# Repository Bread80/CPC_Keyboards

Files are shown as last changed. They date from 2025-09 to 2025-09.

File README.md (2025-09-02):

# Keyboards for Amstrad CPC Computers

This folder contains several designs for Amstrad computers, CPC464, CPC664 and CPC6128. Some can be fitted into the case of an existing machine, all can be used without a case as a replacement for, eg, a bare motherboard including recreations of original motherboards of replacement machines which use the same keyboard layout.

All of the above machines, CPC464, CPC664 and CPC6128, used an identical keyboard matrix although they had slight variations in connectors and pinouts. All of the boards here are suitable for using with any original motherboard. Most of the designs include jumpers or links which can be used to configure them to various mnotherboards. See the individual boards for more detail.

## Available Boards

### [Tactile Switch Keyboard](Tactile/README.md)

This was intended as a cheaper alternative to a full mechanical board. In practice the switches and keycaps used don't offer a huge saving in cost. However, the PCB is significantly smaller (and therefore cheaper), the design doesn't use diodes, and the keycaps can be home-printed and, therefore, modified to your preference.

This design is not (currently) fully documented.

[View...](Tactile/README.md)

### [CPC464 Mechanical with SMT Diodes](Keyswitch_CPC464_SMT/README.md)

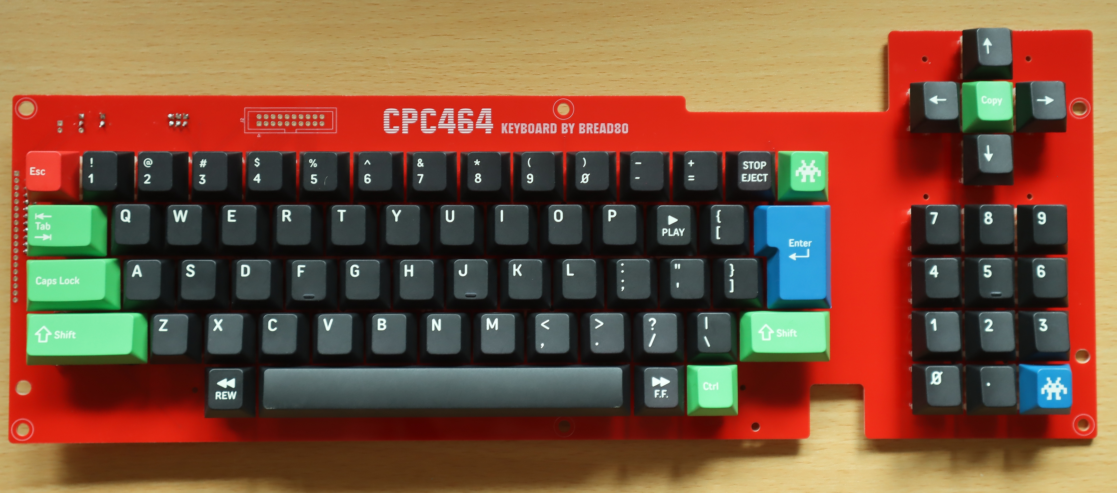
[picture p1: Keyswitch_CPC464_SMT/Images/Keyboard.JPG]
Assembled keyboard


As the heading suggests, this is a board using mechanical keyswitches, and which fits into an original CPC464 case (all variants, as far as we are aware). It includes connector pinouts for both styles of motherboard connector. Solder links allow for use with a CPC6128. See the schematics for how to wire to a CPC664.

The design uses SMT diodes which may present a soldering challenge to some, but the diodes and footprints have been chosen to make soldering as easy as possible.

[View...](Keyswitch_CPC464_SMT/README.md)

### [CPC6128 Mechanical with SMT Diodes](Keyswitch_CPC6128_SMT/README.md)

This board is still at the design stage and NOT suitable for production.

[View...](Keyswitch_CPC6128_SMT/README.md)

## Licence

All designs are licenced under CERN-OHL-P.

You are welcome you sell items for cost plus reasonable postage fees. This allows you to pass on any overages from your PCB fab's minumum order levels. If you want to sell items for profit please talk to us first.

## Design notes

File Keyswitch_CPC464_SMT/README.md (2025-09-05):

# CPC464 Mechanical Keyboard (with SMT Diodes)

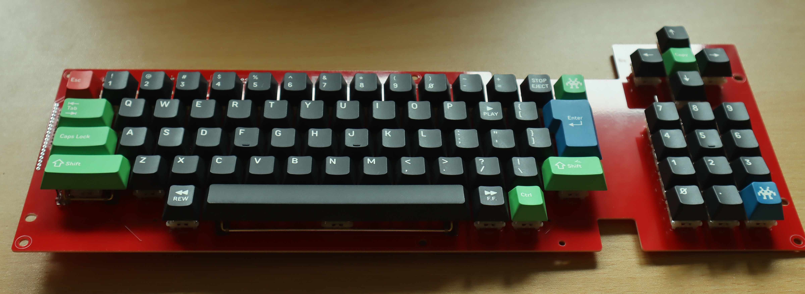
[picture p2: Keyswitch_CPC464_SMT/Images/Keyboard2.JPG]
Assembled keyboard
Assembled keyboard

This project is for an replacement keyboard for an Amstrad CPC464 using Cherry MX compatible keyswitches.

The board is suitable for mounting within an existing CPC464 case and includes connections suitable for both the single row 19/20-pin inline PCB type keyboard and the dual 10-pin connectors used by later membrane keyboards. It can also be used free standing, either with a CPC464 or CPC6128 - jumpers footprints are included to allow remapping of the dual 10-pin connectors. (The keyboard could also be used with a CPC664 but the lines will need remapping between the keyboard and motherboard. The schematic includes details). A third connector footprint is provided at the rear of the board with identical pinout to the 2x10-pin connector (and remapped via the same jumpers). This connector is intended to make the PCB easier to use as a free-standing board when, for example, using with a bare motherboard outside of a case.

Footprints allow either direct soldering of the keyswitches to the board, or the use of MX hotswap sockets. Hotswap sockets allow keyswitches to be more easily swapped for different types or between boards. The board accepts either 3-pin or 5-pin keyswitches but NOTE: There is currently no mounting plate available. We therefore recommend only using 5-pin keyswitches, and NOT 3-pin ones (5-pin switches have two extra mounting lugs on the rear).

The space bar has been reduced in width from the original 9u to a modern standard 7u. The space freed by this has allowed the addition of two 'bonus' keys. These can be mapped, via jumpers, to the main connectors for reading by the host computer, or can be connected to external hardware via the same jumpers.

When fitted into an Amstrad CPC464 case there is a slight gap (0.5u wide, where 1u is one standard key width) to the right of the Enter key. This is, sadly, unavoidable due to available keycap sizes.

## Purchase PCBs

You can download the gerbers from within the repository or purchase PCBs via PCBWay Shared Projects at https://www.pcbway.com/project/shareproject/Mechanical_Keyboard_for_Amstrad_CPC464_e66db4b2.html Disclaimer: we get a small commission if you purchase from PCBWay Shared Projects. This commission helps to fund our other open source projects.

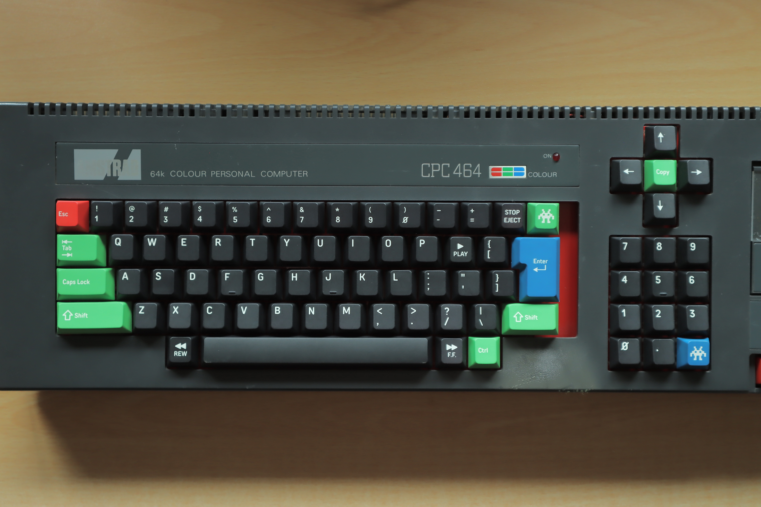
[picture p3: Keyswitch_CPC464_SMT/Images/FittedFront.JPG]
Keyboard fitted into a CPC464 (top view)
Keyboard fitted into a CPC464 (rear view)

## Bill or Materials (BoM)

(This list does not include connectors. See the section below for some connection options).

|Reference|Value|Package|Qty|Notes|
|---|-----|---|---|-----|
|D0-D71,D79,D901,D902|1N4148W|SOD-123|75|If buying from a specialist mechanical keyboard retailer these will be the only surface mount diodes available. We recommend buying a few spares as these are very small and easy to lose.|
|SW0-SW71,SW79,SW901,SW902|MX Hotswap Sockets||75|Optional. Make sure you get the MX type.|
|SW0-SW71,SW79,SW901,SW902|MX Compatible keyswitches||75|Lots of options available. As noted above these should be 5-pin switches.|
|SW0-SW71,SW79,SW901,SW902|MX Compatible keycaps||75|Again of options available. See below for some advice.|
|ST1,ST2|Stabiliser 2u|PCB Mount|2|Use 'PCB Mount'/'screw in' type (NOT plate mount)	Stabilisers are usually supplied in sets which include all necessary parts including mounting screws. Each set will contain more than you need to this project, but make sure you get a set which includes a 7u wire for the space bar.|
|ST3|Stabiliser 7u|PCB Mount|1|(See notes for 2u stabilisers above).|

### Feet

If the board is used free-standing you will probably want to add some feet. The board includes 6(No) M3 mounting holes suitable for this. We would suggest rubber feet at the front and stand-offs at the rear (possibly with rubber feet on the end) to provide some 'raking' to the board.

## Assembly

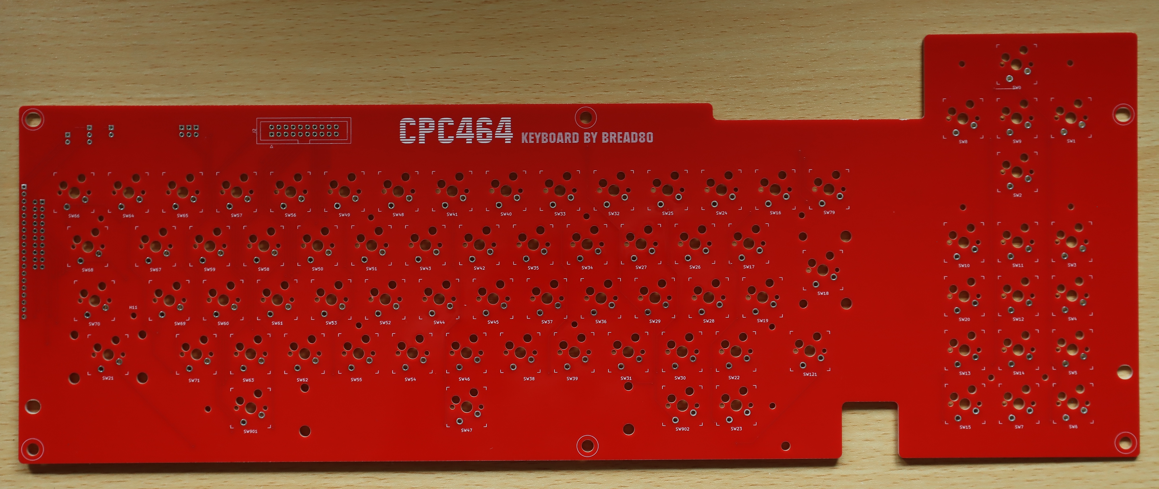
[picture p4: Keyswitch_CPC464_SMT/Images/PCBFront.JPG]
PCB front
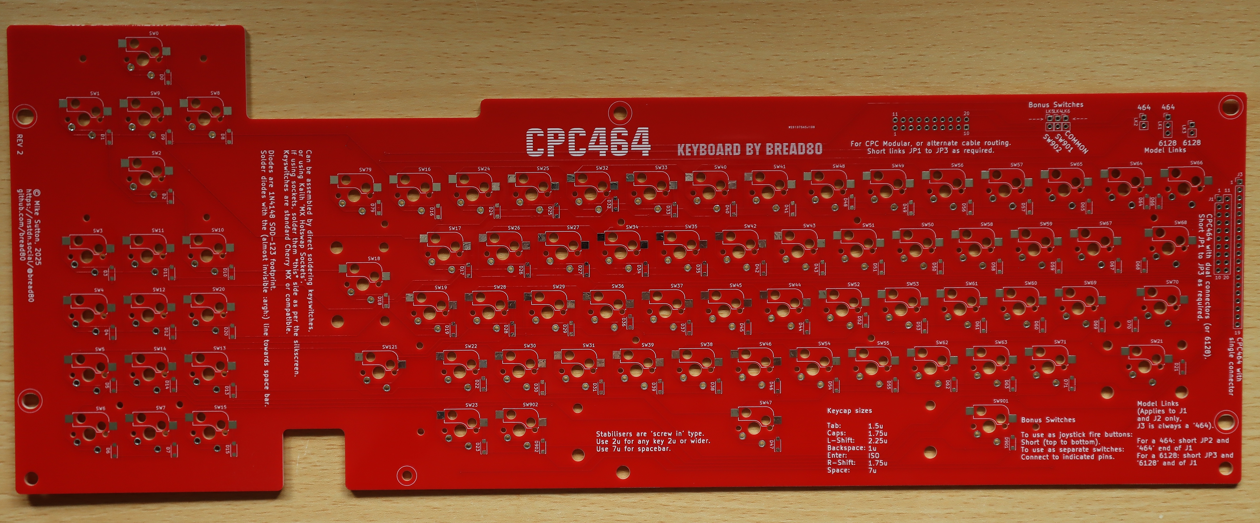
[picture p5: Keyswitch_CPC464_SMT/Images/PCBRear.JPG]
PCB rear

Rear detail

Begin by orienting yourself to the board and, in particular, which side is the top and which the bottom. The top of the board boards the square outlines of the keyswitches, the bottom has the footprints for the hotswap sockets and diodes. Diodes, hotswap sockets (if used) and keyswitches (if not using sockets) are all soldered to the bottom of the board.

We suggest the following assembly sequence.

1. Diodes

Diodes must be installed in the correct orientation. If examined closely you will notice a white line across one end of the diode. On the PCB this end all the diodes must point towards the front (space bar end) of the board. It might be wise to test a few with a multimeter to verify you are have this correct.

2. Hotswap sockets (if using them)

Orient each socket to match the silkscreen and so that the two lugs occupy the holes, then solder each pin.

It's worthwhile checking each socket is fully seated into the board by reheating each pin which pushing the socket with a finger - but take care not to burn your finger! We like to solder all the sockets, then go over one end of every socket. Then, once they have cooled, do the same for the other end of every socket.

3. Connectors and Jumpers (depending on your chosen options - see below)

For jumpers use some wire offcuts - perhaps resistor leads from a previous project?

4. Stabilisers

Check the manufacturers instructions. Pre-assembled ones are fairly straightforward, others are an IQ test which we often fail at on the first go. If the key doesn't press down properly you failed too.

5. Keyswitches (if not using sockets)

These are pretty straightforward. Insert each so that the pins are located in the plated (metalised) holes and fully pushed 'home'. Solder both pins. Double check they are fully seated and, if necessary, reheat while pushing down on the switch.

6. Keyswitches (if using sockets)

This one is easy! Insert the keyswitches, but make sure the pins are mounted into the sockets (this may sound dumb, but they are easily bent).

## Jumper Settings

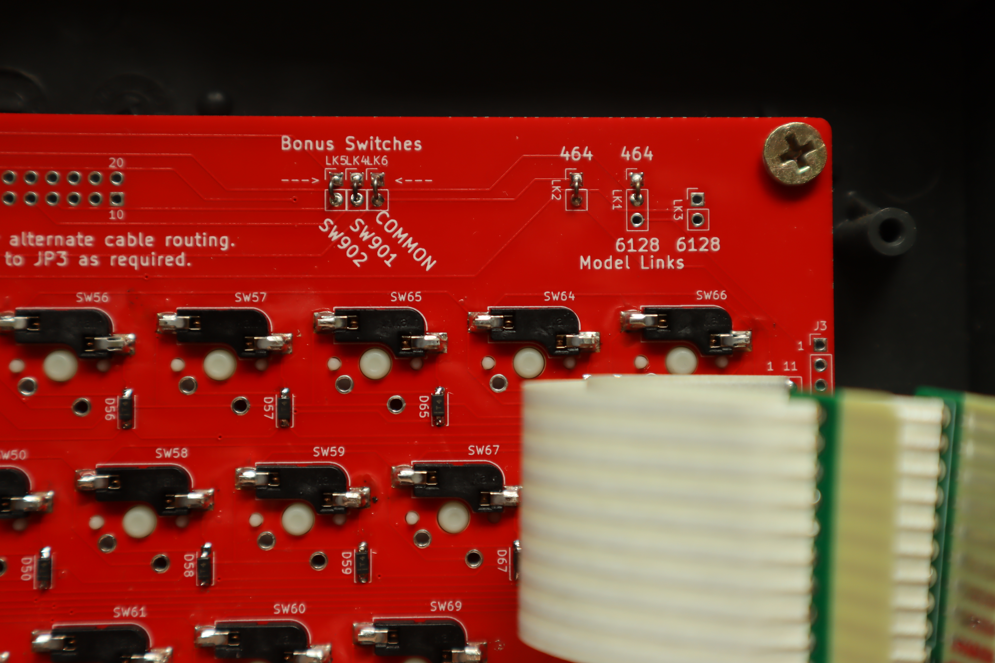
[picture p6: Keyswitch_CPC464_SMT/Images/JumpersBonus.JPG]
Bonus switches and jumpers detail


'Bridging' a solder link entails soldering some bare wire between two pins on the link.

If connecting to a '464 bridge LK2 and the two pins at the '464' end of LK1 (as shown in the photo).

If connecting to a '6128 bridge LK3 and the two pins at the '6128' end of LK3.

(If using the board freestanding and want the flexibility to move it between computers you could also use pin-header with 'shunts' to bridge them. If so you may want to locate them on the top-side of the board).

## Bonus Switches

To map the bonus switches to joystick 1 fire buttons, short the connectors as shown in the photo.

To use as separate switches make connections to three holes indicated by the arrows.

## Installation

The keyboard is attached to the case with five or six screws (depending on the case revision) and replacement is straightforward. Take care not to overtighten the screws as the threads in the plastic case are easy to strip.

The spade terminal ground connection cannot be connected to the new PCB and will need to be covered with electrical insulation tape or similar to prevent it shorting anything.

## Connecting to the motherboard

Connection options depend on your motherboard revision. We are open to feedback and suggestions for better options.

### Single Row Motherboards (PCB style keyboards)

Amstrad appear to have used two different connector styles over the life of the machine. Sadly neither of these seem to be still available. The best option is probably replacing the motherboard header with something which is available, and directly soldering wires to the keyboard PCB (as per original Amstrad keyboards).

### Double Row Motherboards (membrane style keyboards)

PCBs are available which can slot into the motherboard connectors. We have our own available at https://github.com/Bread80/Keyboard-FPC10  The motherboard connectors are single sided and the PCBs will need to be assembled to match. Note that these PCBs must be manufactured to a suitable thickness for inserting into the sockets.

Our preference is to use FFC/FPC cables (with 2.54mm pin pitch) to connect these to the keyboard, the other end being direct soldered to the board.

## Keycaps

There is, obviously, a wide selection of keycaps available. In the board shown in the photos we've used the lovely Amstrad inspired set available at https://finalkeystudio.com/products/amstrad-cpc-464-keycaps-set which has both '464 and '6128 inspired options. Sadly the set  doesn't cover ever key you'll need (note the CLR and DEL keys in the photos) but there are plenty of other keys which can be used to substitute. The set also uses 'standard' layout for (eg) symbols rather than (any of) the Amstrad layout(s). (We have no connection to the designer or seller, and can't offer buying advice, but we do love the keycaps).

When selecting a set you'll need one which includes the following key widths:
|Key|Width|
|---|-----|
|Tab|1.5u|
|Caps|1.75u|
|Left Shift|2.25u|
|Backspace|1u|
|Enter|ISO standard|
|Right Shift|1.75u|
|Space bar|7u|

It's also worth noting that you're unlikely to find a set which matches the Amstrad symbol layout. If rearranging keys note that keycap profiles are different for every row and swapping keys between rows may not be ideal.

Rather than re-arranging the keys the Amstrad firmware has support for remapping the layout in software. This is (currently) left as an exercise for the reader.

## Schematic

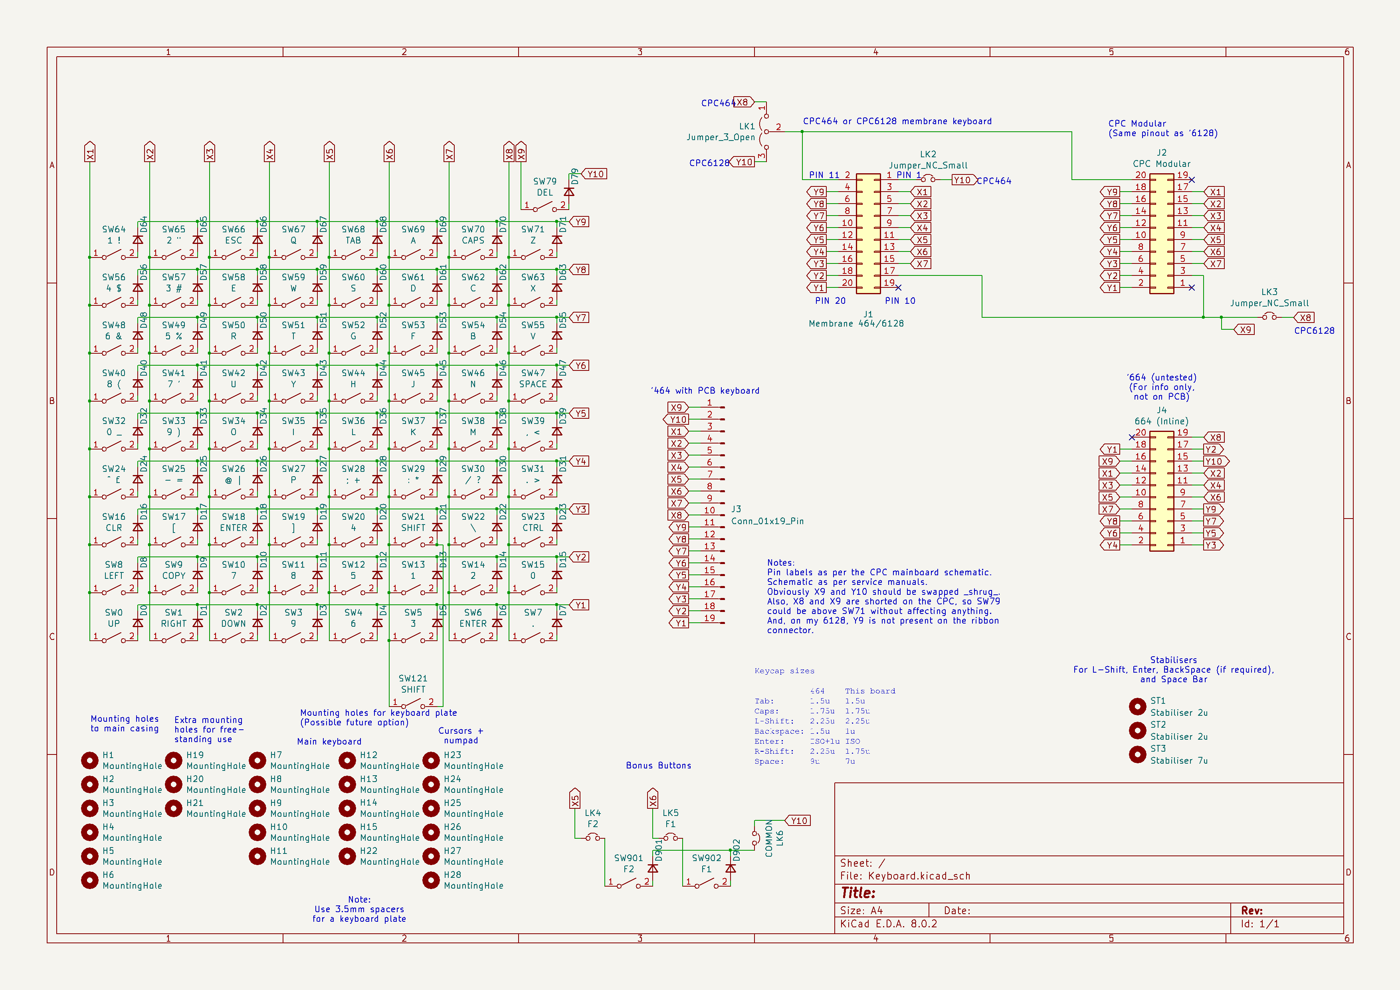
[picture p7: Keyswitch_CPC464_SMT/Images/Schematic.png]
Schematic


## Licence

CERN-OHL-P

You are welcome you sell items for cost plus reasonable postage fees. This allows you to pass on any overages from your PCB fab's minimum order levels. If you want to sell items for profit please talk to us first.

## More Images

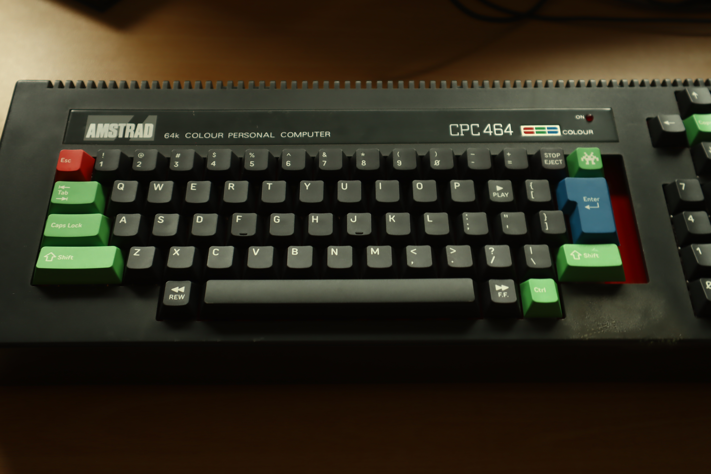
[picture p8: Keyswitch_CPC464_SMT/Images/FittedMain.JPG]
Fitted main section

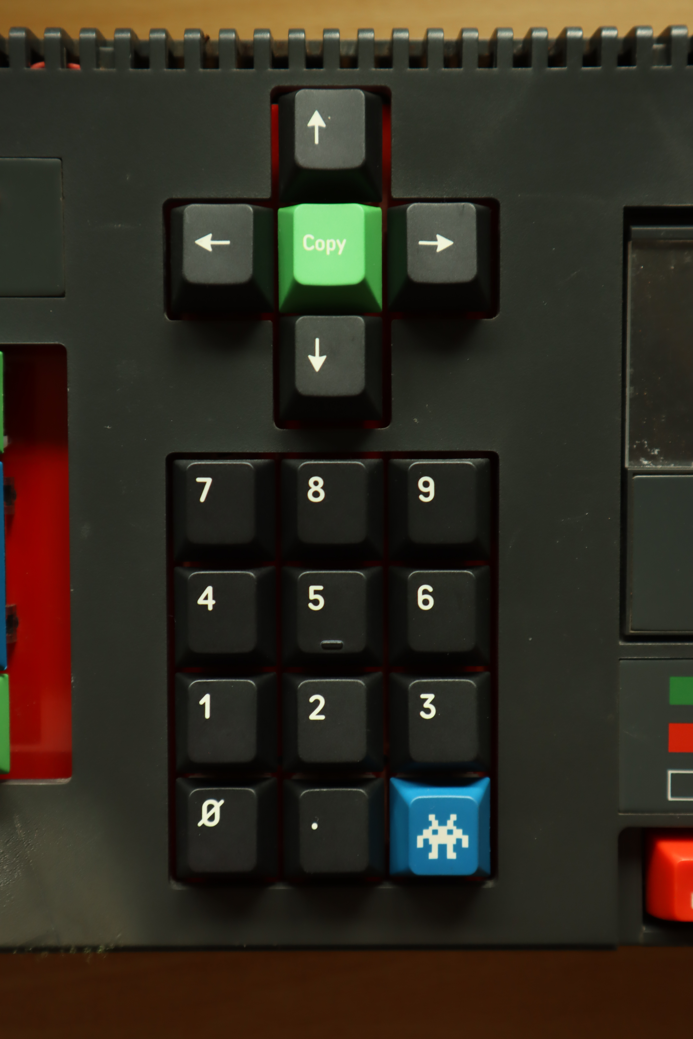
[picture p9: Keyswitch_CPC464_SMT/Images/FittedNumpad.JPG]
Fitted number pad

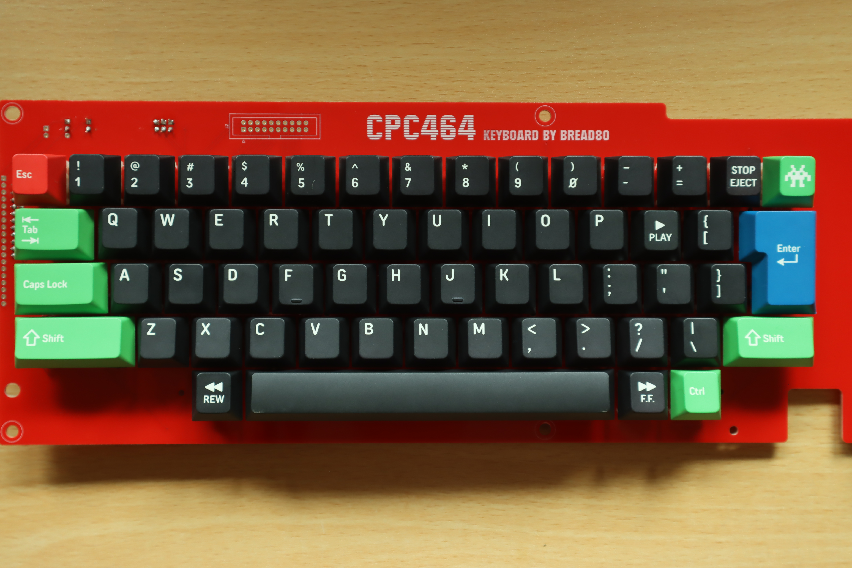
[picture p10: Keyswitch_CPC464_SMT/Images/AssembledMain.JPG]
Assembled main section

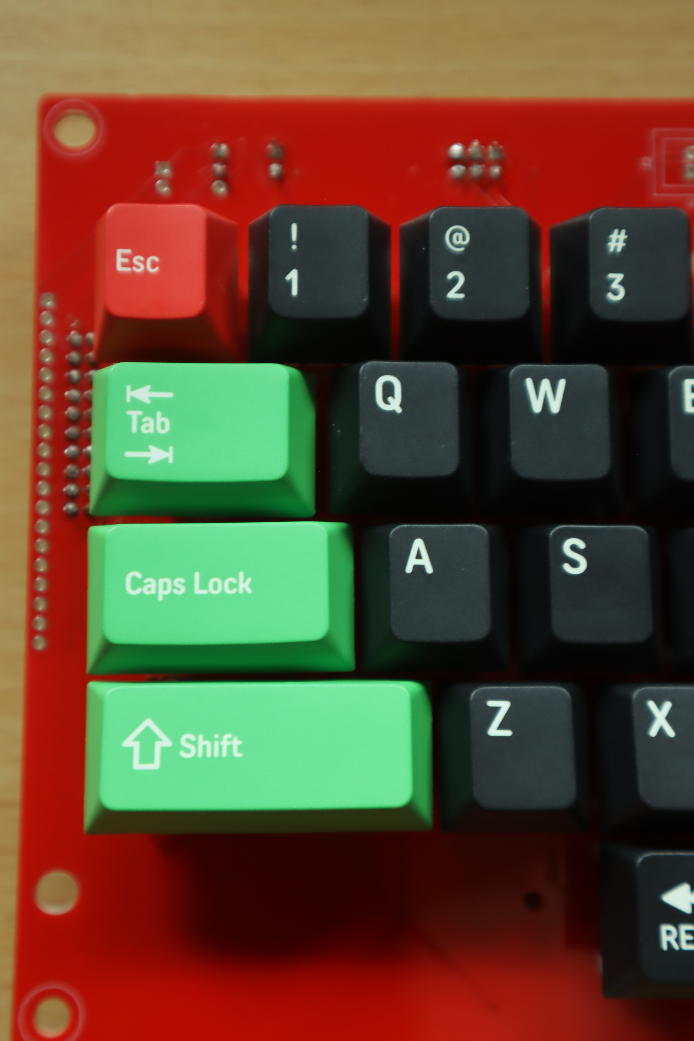
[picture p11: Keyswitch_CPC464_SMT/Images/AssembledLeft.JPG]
Left end of assembled board

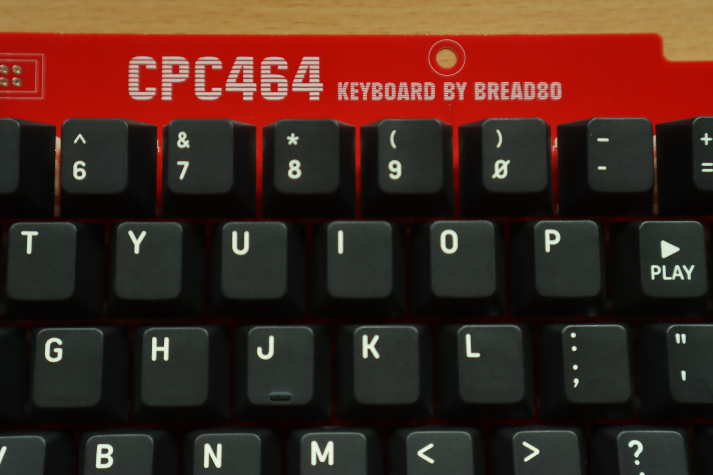
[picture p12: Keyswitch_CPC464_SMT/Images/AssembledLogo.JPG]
Detail of logo on assembled board

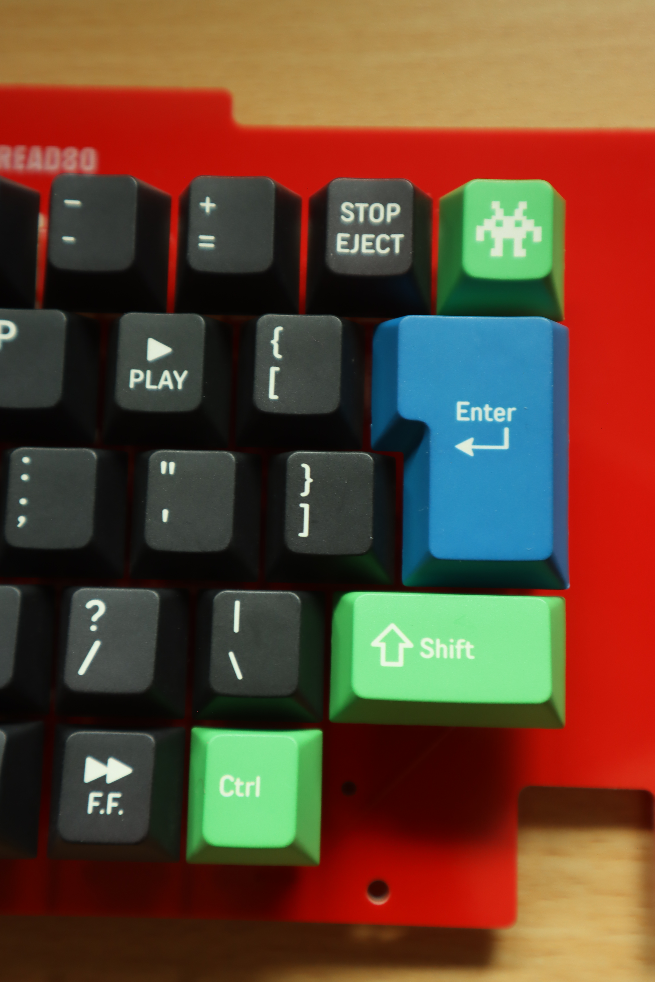
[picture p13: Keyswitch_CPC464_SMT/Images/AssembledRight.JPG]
Right end of assembled board

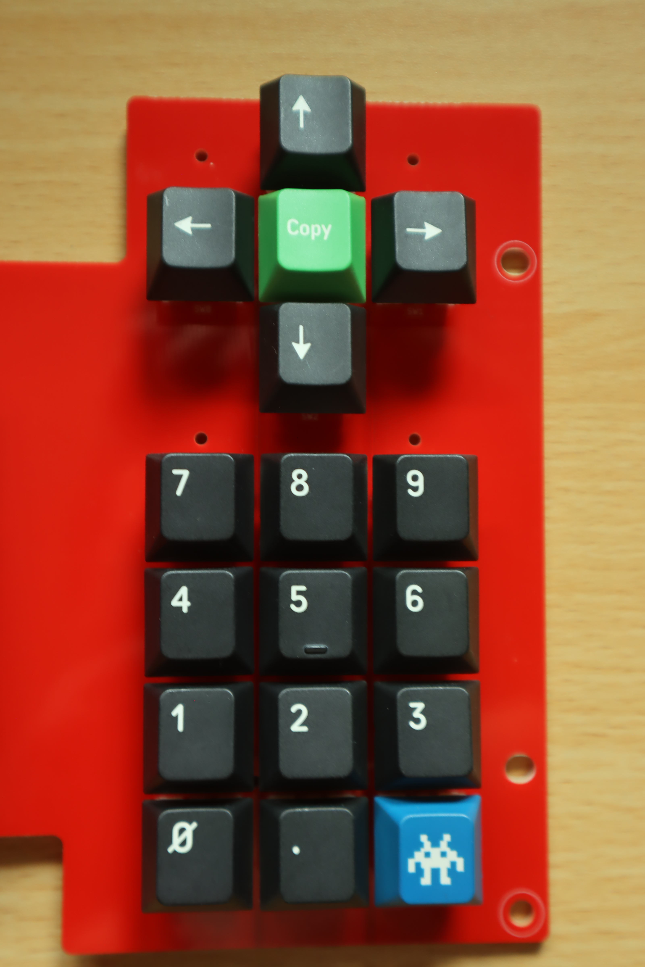
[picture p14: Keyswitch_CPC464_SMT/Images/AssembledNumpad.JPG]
Assembled number pad

Assembled PCB, read
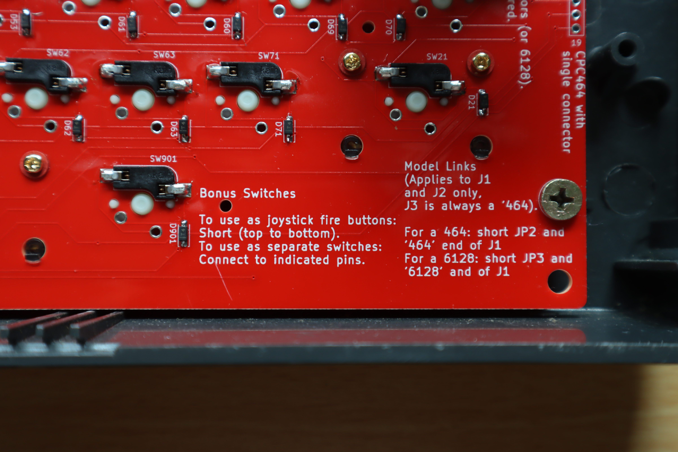
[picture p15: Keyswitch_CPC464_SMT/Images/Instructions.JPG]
Assembled instructions detail


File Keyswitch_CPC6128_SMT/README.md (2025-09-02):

# CPC6128 Mechanical Keyboard (with SMT Diodes)

This project is still in the design stages.

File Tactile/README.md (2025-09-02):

# Keyboard for Amstrad CPC Computers

This project is a keyboard suitable for direct connection to an Amstrad CPC. The PCB uses tactile switches which can easily be labelled with suitable legends for the keytops. The current layout is that of an Amstrad CPC6128, but the key matrix is the same across all machines. The only differences are in the connector types and pinouts.

This board has connectors which are compatible with:
* CPC464 with PCB keyboard (1x20 pin connector)
* CPC464 with membrane keyboard (2x10 pin connectors)
* CPC664 (1x20 pin connector) **Untested**
* CPC6128 (2x10 pin connectors)

Plus machines: I'm not clear whether they use the same keyboard pinout or not. As such I can't say whether this board works with them or not.

Sadly it's not practical to add mounting holes suitable for mounting the keyboard on top of the CPC mainboard.

The repository includes an SVG file with key legend. This is suitable for the open source [Inkscape](https://inkscape.org) software

## BoM

74x Key switches[1]: Alps Apline SKHCBEA010. Mouser no: 688-SKHCBEA010
74x Keytops + Keycaps[2][3]: Alps Alpine SK2AA00090. Mouser: 688-SK2AA00090
'Standard pin header' (2.54mm spacing)[4]
2x Shunts[4]
Connector(s) (to keyboard)[5]
Connector(s) (to CPC)[6]
Cable (keyboard to CPC)[7]
5x Standoffs, short)[8]: 13mm length, M3 x 0.5, 4.5mm OD, female/female. Mouser: M1260-3005-SS
5x Standoffs, long)[8]: 25mm, M3 x 0.5, 4.5mm OD, female/female. Mouser: 761-M1272-3005-SS
10x Screws[8]: M3 x 6mm. Mouser: 534-9191-3
--also-- key legend (printout)[9]

### Notes:
Mouser codes can be used at http://mouser.com
[1] PCB will accept any generic 12mm 'tactile switch'. The specified model allows a keytop + keycap to be attched. This enables a printed key legend to be used. The same design is available engineered for 'operating force' values. In my tests this model had the best feel.
[2] Other colours are available (for the keytops), product codes SK2AA000x0 where x is 6,7,8,9 (NOTE: other digits are different products!).
[3] This product code includes both keycap and keytop. These are also available separately, but the combined pack is slightly cheaper.
Consult the keyswitch data sheet for the full list of available options: https://www.mouser.co.uk/datasheet/2/15/SKHC-1370786.pdf

[4] For configuration jumpers. Source from ebay etc for sensible pricing. If you don't intend to change settings you can solder an offcut of wire instead.
[5] Unless you need to attach multiple machines your best option here is to directly solder wire to the board. Otherwise pin header is probably the most convenient. You'll either need 1x20 or 2x10 depending on the machine, plus 
[6] Options here depend on your machine. The 20-pin inline connect machines will accept 'Dupont' style connectors, pin header etc. The 2x10 matrix connectors are more of a pin. I've successfully used FPC/FFC cable. With some patience this can be persuaded into the connector. These cables only seem to be available in very short lengths but ribbon (etc) cable can be soldered to the other end to run to the keyboard. Obviously some insulation will be helpful on the joins to prevent it shorting against anything (or each other)! You'll need 2x 10-pin cables, 571-FSN-21A-10 is a suitable Mouser product code.
[7] Discreet cables or a length or ribbon cable is up to you. Not every line is connected but using a 20pin or 2x 10-pin ribbon cable saves you having to etsablish which aren't needed. Cable length is up to you but anything too short will make it difficult to position the keyboard where you want it. I'd suggest a /minimum/ of about eight inches (40cm).
[8] I use standoffs as feet to lift to board of the desk and give space for the wiring underneath. You can give the keyboard some 'raking' by using longer ones at the rear. another option is to use a male/female standoff as an extender. The board is engineered for M3 screws/threads. Note: The PCB has three rows of mounting holes but the central row has not proved necessary and I'll remove them if I do an update. Just use the top and bottom rows.
[9] Provided as an SVG suitable for Inkscape) in this here repository. If creating your own key legend, each key needs to be a maximum 10mm x 10mm

## Known Issues

* The keyswitches have a pair of small lugs on the underside. Fitting them would be easier if the board had siutable holes for them. As is it just needs some care to ensure each switch sits flag and true.

## Assembly guide

### Soldering:
* Pin header. Solder the pin header strips for the settings jumpers. Pin header can easily be snapped into short sections as needed.
* Start with the keyswitches. Mount them any way which fits the holes and you'll be okay! Note that there are small lugs on the underside which make them want to sit at an angle. I /strongly/ recommend taking some care to check they are sitting flat and level. My method is to solder a single leg on each, then inspect and rework as needed to level them. Once they're level solder the remaining pins.
* Connectors. Solder your preference of connector(s), or wire, to the rear of the board. The required connectors are as follows:
For a CPC464 with PCB keyboard: connector J1 (1x20 pin)
For a CPC464 with matrix keyboard: connectors J2 and J3 (2 of 1x10 pin)
For a CPC664: connector J4 (1x20 pin)
For a CPC6128: connectors J2 and J3 (2 of 1x10 pin)

### Keycaps:
* Print out the key legend sheet and cut up. Cutting as accurately to the lines as possible will be beneficial. If you have them available, using a cutting board, craft knife, and steel ruler will probably give a better finish than scissors.
* Before assembling the key top + key legend + key cap consult the assembly diagram at the bottom of page three of the datasheet: https://www.mouser.co.uk/datasheet/2/15/SKHC-1370786.pdf Note the recommended orientation of keytop to keycap and plan which way you'll need to assemble things so your legend ends up the correct way around!
* With the keycap (clear plastic piece) face down on the bench, insert the key legend (paper) face down. Then insert the keytop into the keycap, taking note of the corrent orientation with respect to the key legend.
* Attach the keytop/keycaps to the keyswitches.

### Configuration and Connection

All the connectors are orientated in the same way as those on the Amstrad motherboard. I.e. the pin(s) towards the top of rear of the keyboard PCB are those towards the rear of the motherboard PCB and, for the the dual 10-pin connectors, the right-most connector on the keyboard PCB (when viewed from the top) connects to the right-most connector on the motherboard PCB.

Configuration is *only* needed if using the pair of 10-pin connectors to connect to the motherboard. If connecting to a CPC464, short (with a 'shunt') JP2 and the left-most two pins of JP1. If connecting to a CPC6128 short JP3 and the two right-most pins of JP1. Note that when connecting to a CPC464 JP3 should be left open, when connecting to a CPC6128 JP2 should be left open.

## Keyboard legend file(s)

Keyboard legend files are in the 'legend' folder. The following designs/layouts are available. SVG files can be created, edited and printed with the open source Inkscape software. If you create anything new/interesting please contribute it back to the repository.

UK-CPC6128-with-464-colours.svg - Amstrad CPC6128 layout with UK legend using the colour scheme of an original Amstrad CPC464.

## Licence

My aim with this project is to share something potentially useful with the community but I don't want to see my work being exploited for profit.

Therefore, it's okay to have a board manufactured for your own use and sell off the spare boards for an amount to cover your costs and postage. If you want to sell boards, or derivatives, for profit or as part of a business then talk to me first.

## Contact

Website: https://bread80.com
Github: https://github.com/Bread80
Mastodon: https://mstdn.social/@bread80
Twitter: https://twitter.com/bread80com

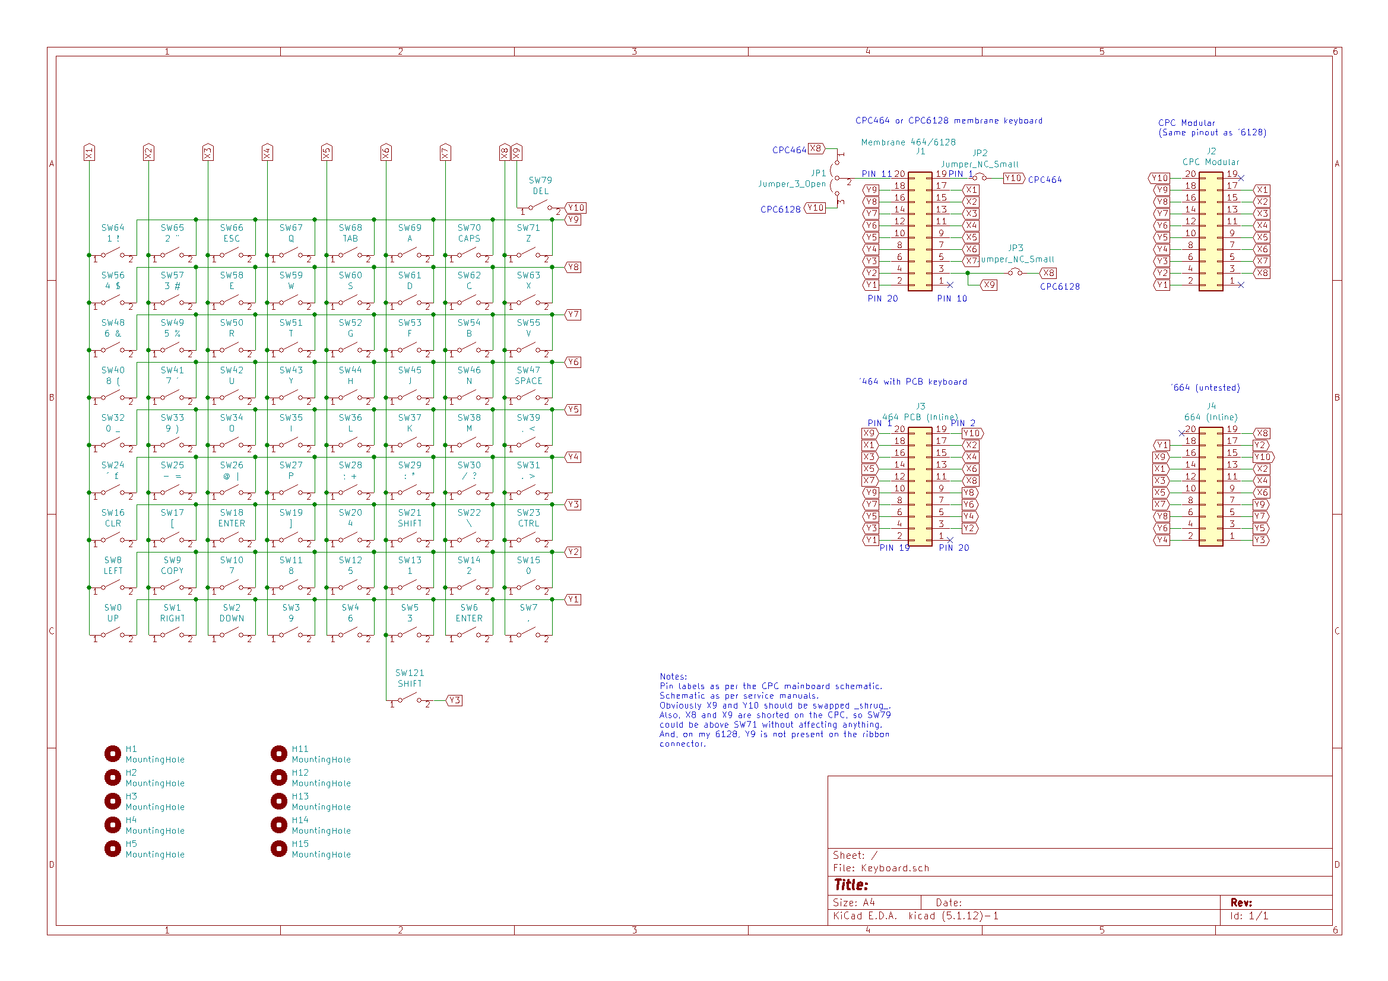
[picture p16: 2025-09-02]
Keyswitch_CPC6128_SMT/Schematic.png

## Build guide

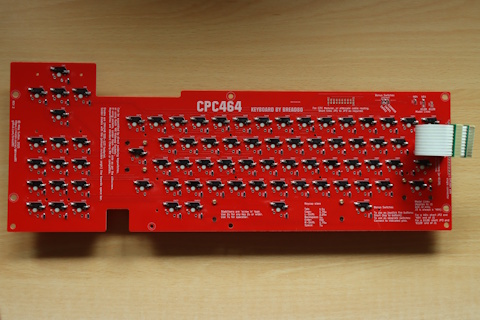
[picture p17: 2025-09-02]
Keyswitch_CPC464_SMT/Images/AssembledRear-small.jpg

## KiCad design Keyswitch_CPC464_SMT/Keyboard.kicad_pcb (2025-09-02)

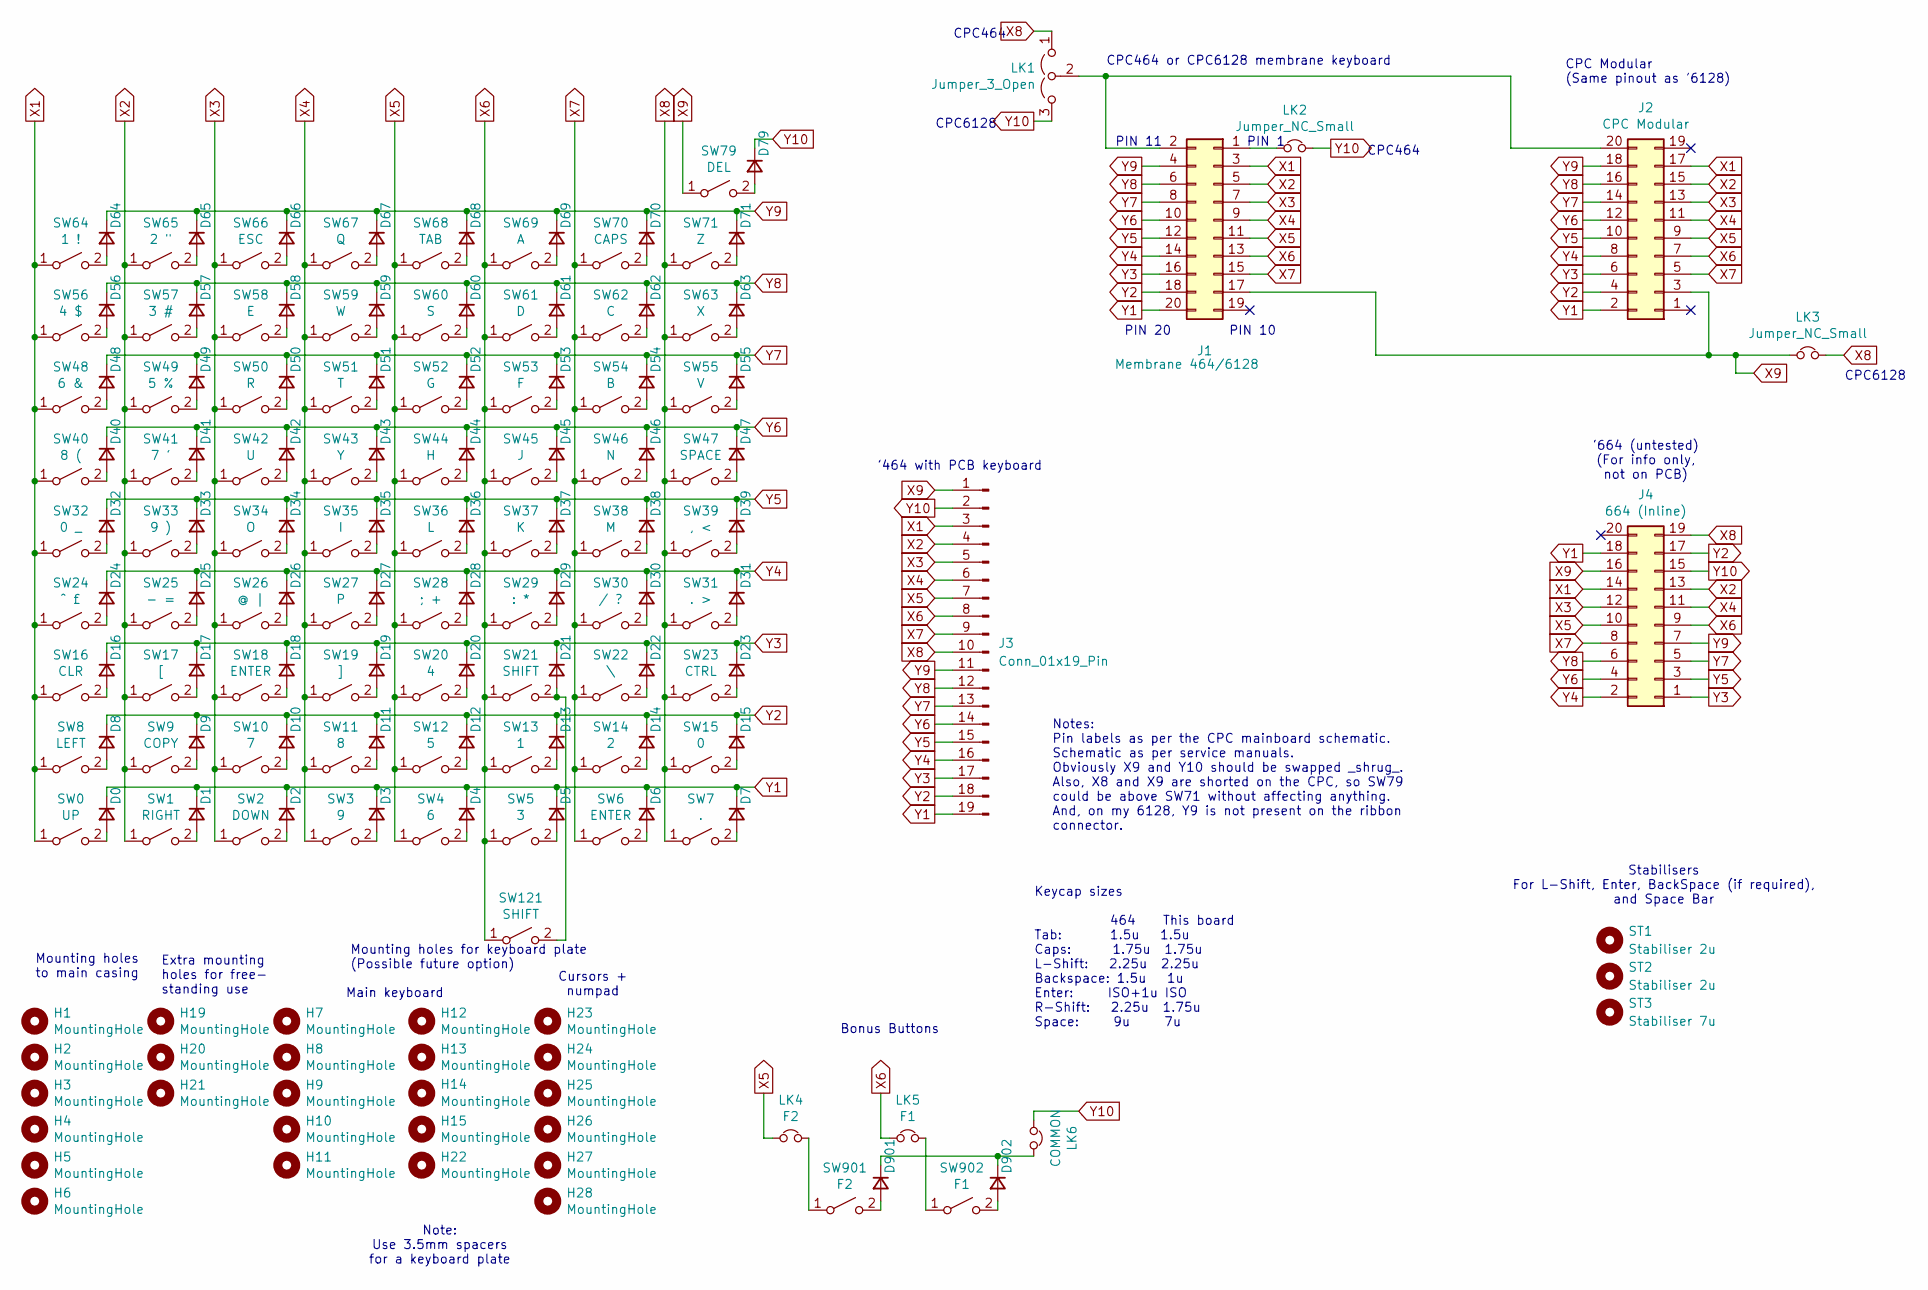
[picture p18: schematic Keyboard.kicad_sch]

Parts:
D0, D1, D2, D3, D4, D5, D6, D7, D8, D9, D10, D11, D12, D13, D14, D15, D16, D17, D18, D19, D20, D21, D22, D23, D24, D25, D26, D27, D28, D29, D30, D31, D32, D33, D34, D35, D36, D37, D38, D39, D40, D41, D42, D43, D44, D45, D46, D47, D48, D49, D50, D51, D52, D53, D54, D55, D56, D57, D58, D59, D60, D61, D62, D63, D64, D65, D66, D67, D68, D69, D70, D71, D79, D901, D902: 1N4148; D_SOD-123-Handsolder
H1, H3, H4, H6: MountingHole; MountingHole4.3mmx5.3mmNPTH
H2, H19, H20, H21: MountingHole; MountingHole_4.3mm_M4_DIN965
H5: MountingHole; MountingHole_3.2mm_M3_DIN965
H7, H8, H9, H10, H11, H12, H13, H14, H15, H22, H23, H24, H25, H26, H27, H28: MountingHole; MountingHole_2.2mm_M2_DIN965
J1: Membrane 464/6128; PinHeader_2x10_P2.54mm_Vertical
J2: CPC Modular; IDC-Header_2x10_P2.54mm_Vertical
J3: Conn_01x19_Pin; PinHeader_1x19_P2.54mm_Vertical
J4: 664 (Inline); IDC-Header_2x10_P2.54mm_Vertical
LK1: Jumper_3_Open; PinHeader_1x03_P2.54mm_Vertical
LK2, LK3: Jumper_NC_Small; PinHeader_1x02_P2.54mm_Vertical
LK4: F2; PinHeader_1x02_P2.54mm_Vertical
LK5: F1; PinHeader_1x02_P2.54mm_Vertical
LK6: COMMON; PinHeader_1x02_P2.54mm_Vertical
ST1, ST2: Stabiliser 2u; Stabilizer_MX_2u
ST3: Stabiliser 7u; Stabilizer_MX_7u
SW0: UP; Kailh_socket_MX_optional
SW1: RIGHT; Kailh_socket_MX_optional
SW2: DOWN; Kailh_socket_MX_optional
SW3: 9; Kailh_socket_MX_optional
SW4: 6; Kailh_socket_MX_optional
SW5: 3; Kailh_socket_MX_optional
SW6, SW18: ENTER; Kailh_socket_MX_optional
SW7: .; Kailh_socket_MX_optional
SW8: LEFT; Kailh_socket_MX_optional
SW9: COPY; Kailh_socket_MX_optional
SW10: 7; Kailh_socket_MX_optional
SW11: 8; Kailh_socket_MX_optional
SW12: 5; Kailh_socket_MX_optional
SW13: 1; Kailh_socket_MX_optional
SW14: 2; Kailh_socket_MX_optional
SW15: 0; Kailh_socket_MX_optional
SW16: CLR; Kailh_socket_MX_optional
SW17: [; Kailh_socket_MX_optional
SW19: ]; Kailh_socket_MX_optional
SW20: 4; Kailh_socket_MX_optional
SW21, SW121: SHIFT; Kailh_socket_MX_optional
SW22: \; Kailh_socket_MX_optional
SW23: CTRL; Kailh_socket_MX_optional
SW24: ^ £; Kailh_socket_MX_optional
SW25: - =; Kailh_socket_MX_optional
SW26: @ |; Kailh_socket_MX_optional
SW27: P; Kailh_socket_MX_optional
SW28: ; +; Kailh_socket_MX_optional
SW29: : *; Kailh_socket_MX_optional
SW30: / ?; Kailh_socket_MX_optional
SW31: . >; Kailh_socket_MX_optional
SW32: 0 _; Kailh_socket_MX_optional
SW33: 9 ); Kailh_socket_MX_optional
SW34: O; Kailh_socket_MX_optional
SW35: I; Kailh_socket_MX_optional
SW36: L; Kailh_socket_MX_optional
SW37: K; Kailh_socket_MX_optional
SW38: M; Kailh_socket_MX_optional
SW39: , <; Kailh_socket_MX_optional
SW40: 8 (; Kailh_socket_MX_optional
SW41: 7 '; Kailh_socket_MX_optional
SW42: U; Kailh_socket_MX_optional
SW43: Y; Kailh_socket_MX_optional
SW44: H; Kailh_socket_MX_optional
SW45: J; Kailh_socket_MX_optional
SW46: N; Kailh_socket_MX_optional
SW47: SPACE; Kailh_socket_MX_optional
SW48: 6 &; Kailh_socket_MX_optional
SW49: 5 %; Kailh_socket_MX_optional
SW50: R; Kailh_socket_MX_optional
SW51: T; Kailh_socket_MX_optional
SW52: G; Kailh_socket_MX_optional
SW53: F; Kailh_socket_MX_optional
SW54: B; Kailh_socket_MX_optional
SW55: V; Kailh_socket_MX_optional
SW56: 4 $; Kailh_socket_MX_optional
SW57: 3 #; Kailh_socket_MX_optional
SW58: E; Kailh_socket_MX_optional
SW59: W; Kailh_socket_MX_optional
SW60: S; Kailh_socket_MX_optional
SW61: D; Kailh_socket_MX_optional
SW62: C; Kailh_socket_MX_optional
SW63: X; Kailh_socket_MX_optional
SW64: 1 !; Kailh_socket_MX_optional
SW65: 2 "; Kailh_socket_MX_optional
SW66: ESC; Kailh_socket_MX_optional
SW67: Q; Kailh_socket_MX_optional
SW68: TAB; Kailh_socket_MX_optional
SW69: A; Kailh_socket_MX_optional
SW70: CAPS; Kailh_socket_MX_optional
SW71: Z; Kailh_socket_MX_optional
SW79: DEL; Kailh_socket_MX_optional
SW901: F2; Kailh_socket_MX_optional
SW902: F1; Kailh_socket_MX_optional

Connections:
unnamed: D0.2 (A), SW0.2 (B)
unnamed: D1.2 (A), SW1.2 (B)
unnamed: D2.2 (A), SW2.2 (B)
unnamed: D3.2 (A), SW3.2 (B)
unnamed: D4.2 (A), SW4.2 (B)
unnamed: D5.2 (A), SW5.2 (B)
unnamed: D6.2 (A), SW6.2 (B)
unnamed: D7.2 (A), SW7.2 (B)
unnamed: D8.2 (A), SW8.2 (B)
unnamed: D9.2 (A), SW9.2 (B)
unnamed: D10.2 (A), SW10.2 (B)
unnamed: D11.2 (A), SW11.2 (B)
unnamed: D12.2 (A), SW12.2 (B)
unnamed: D13.2 (A), SW13.2 (B)
unnamed: D14.2 (A), SW14.2 (B)
unnamed: D15.2 (A), SW15.2 (B)
unnamed: D16.2 (A), SW16.2 (B)
unnamed: D17.2 (A), SW17.2 (B)
unnamed: D18.2 (A), SW18.2 (B)
unnamed: D19.2 (A), SW19.2 (B)
unnamed: D20.2 (A), SW20.2 (B)
unnamed: D21.2 (A), SW21.2 (B), SW121.2 (B)
unnamed: D22.2 (A), SW22.2 (B)
unnamed: D23.2 (A), SW23.2 (B)
unnamed: D24.2 (A), SW24.2 (B)
unnamed: D25.2 (A), SW25.2 (B)
unnamed: D26.2 (A), SW26.2 (B)
unnamed: D27.2 (A), SW27.2 (B)
unnamed: D28.2 (A), SW28.2 (B)
unnamed: D29.2 (A), SW29.2 (B)
unnamed: D30.2 (A), SW30.2 (B)
unnamed: D31.2 (A), SW31.2 (B)
unnamed: D32.2 (A), SW32.2 (B)
unnamed: D33.2 (A), SW33.2 (B)
unnamed: D34.2 (A), SW34.2 (B)
unnamed: D35.2 (A), SW35.2 (B)
unnamed: D36.2 (A), SW36.2 (B)
unnamed: D37.2 (A), SW37.2 (B)
unnamed: D38.2 (A), SW38.2 (B)
unnamed: D39.2 (A), SW39.2 (B)
unnamed: D40.2 (A), SW40.2 (B)
unnamed: D41.2 (A), SW41.2 (B)
unnamed: D42.2 (A), SW42.2 (B)
unnamed: D43.2 (A), SW43.2 (B)
unnamed: D44.2 (A), SW44.2 (B)
unnamed: D45.2 (A), SW45.2 (B)
unnamed: D46.2 (A), SW46.2 (B)
unnamed: D47.2 (A), SW47.2 (B)
unnamed: D48.2 (A), SW48.2 (B)
unnamed: D49.2 (A), SW49.2 (B)
unnamed: D50.2 (A), SW50.2 (B)
unnamed: D51.2 (A), SW51.2 (B)
unnamed: D52.2 (A), SW52.2 (B)
unnamed: D53.2 (A), SW53.2 (B)
unnamed: D54.2 (A), SW54.2 (B)
unnamed: D55.2 (A), SW55.2 (B)
unnamed: D56.2 (A), SW56.2 (B)
unnamed: D57.2 (A), SW57.2 (B)
unnamed: D58.2 (A), SW58.2 (B)
unnamed: D59.2 (A), SW59.2 (B)
unnamed: D60.2 (A), SW60.2 (B)
unnamed: D61.2 (A), SW61.2 (B)
unnamed: D62.2 (A), SW62.2 (B)
unnamed: D63.2 (A), SW63.2 (B)
unnamed: D64.2 (A), SW64.2 (B)
unnamed: D65.2 (A), SW65.2 (B)
unnamed: D66.2 (A), SW66.2 (B)
unnamed: D67.2 (A), SW67.2 (B)
unnamed: D68.2 (A), SW68.2 (B)
unnamed: D69.2 (A), SW69.2 (B)
unnamed: D70.2 (A), SW70.2 (B)
unnamed: D71.2 (A), SW71.2 (B)
unnamed: D79.2 (A), SW79.2 (B)
unnamed: D901.2 (A), SW901.2 (B)
unnamed: D901.1 (K), D902.1 (K), LK6.1
unnamed: D902.2 (A), SW902.2 (B)
unnamed: J1.1, LK2.2
unnamed: J1.2, J2.20, LK1.2 (C)
unnamed: LK4.1, SW901.1 (A)
unnamed: LK5.1, SW902.1 (A)
X1: J1.3, J2.17, J3.3, J4.14, SW0.1 (A), SW8.1 (A), SW16.1 (A), SW24.1 (A), SW32.1 (A), SW40.1 (A), SW48.1 (A), SW56.1 (A), SW64.1 (A)
X2: J1.5, J2.15, J3.4, J4.13, SW1.1 (A), SW9.1 (A), SW17.1 (A), SW25.1 (A), SW33.1 (A), SW41.1 (A), SW49.1 (A), SW57.1 (A), SW65.1 (A)
X3: J1.7, J2.13, J3.5, J4.12, SW2.1 (A), SW10.1 (A), SW18.1 (A), SW26.1 (A), SW34.1 (A), SW42.1 (A), SW50.1 (A), SW58.1 (A), SW66.1 (A)
X4: J1.9, J2.11, J3.6, J4.11, SW3.1 (A), SW11.1 (A), SW19.1 (A), SW27.1 (A), SW35.1 (A), SW43.1 (A), SW51.1 (A), SW59.1 (A), SW67.1 (A)
X5: J1.11, J2.9, J3.7, J4.10, LK4.2, SW4.1 (A), SW12.1 (A), SW20.1 (A), SW28.1 (A), SW36.1 (A), SW44.1 (A), SW52.1 (A), SW60.1 (A), SW68.1 (A)
X6: J1.13, J2.7, J3.8, J4.9, LK5.2, SW5.1 (A), SW13.1 (A), SW21.1 (A), SW29.1 (A), SW37.1 (A), SW45.1 (A), SW53.1 (A), SW61.1 (A), SW69.1 (A), SW121.1 (A)
X7: J1.15, J2.5, J3.9, J4.8, SW6.1 (A), SW14.1 (A), SW22.1 (A), SW30.1 (A), SW38.1 (A), SW46.1 (A), SW54.1 (A), SW62.1 (A), SW70.1 (A)
X8: J3.10, J4.19, LK1.1 (A), LK3.1, SW7.1 (A), SW15.1 (A), SW23.1 (A), SW31.1 (A), SW39.1 (A), SW47.1 (A), SW55.1 (A), SW63.1 (A), SW71.1 (A)
X9: J1.17, J2.3, J3.1, J4.16, LK3.2, SW79.1 (A)
Y1: D0.1 (K), D1.1 (K), D2.1 (K), D3.1 (K), D4.1 (K), D5.1 (K), D6.1 (K), D7.1 (K), J1.20, J2.2, J3.19, J4.18
Y2: D8.1 (K), D9.1 (K), D10.1 (K), D11.1 (K), D12.1 (K), D13.1 (K), D14.1 (K), D15.1 (K), J1.18, J2.4, J3.18, J4.17
Y3: D16.1 (K), D17.1 (K), D18.1 (K), D19.1 (K), D20.1 (K), D21.1 (K), D22.1 (K), D23.1 (K), J1.16, J2.6, J3.17, J4.1
Y4: D24.1 (K), D25.1 (K), D26.1 (K), D27.1 (K), D28.1 (K), D29.1 (K), D30.1 (K), D31.1 (K), J1.14, J2.8, J3.16, J4.2
Y5: D32.1 (K), D33.1 (K), D34.1 (K), D35.1 (K), D36.1 (K), D37.1 (K), D38.1 (K), D39.1 (K), J1.12, J2.10, J3.15, J4.3
Y6: D40.1 (K), D41.1 (K), D42.1 (K), D43.1 (K), D44.1 (K), D45.1 (K), D46.1 (K), D47.1 (K), J1.10, J2.12, J3.14, J4.4
Y7: D48.1 (K), D49.1 (K), D50.1 (K), D51.1 (K), D52.1 (K), D53.1 (K), D54.1 (K), D55.1 (K), J1.8, J2.14, J3.13, J4.5
Y8: D56.1 (K), D57.1 (K), D58.1 (K), D59.1 (K), D60.1 (K), D61.1 (K), D62.1 (K), D63.1 (K), J1.6, J2.16, J3.12, J4.6
Y9: D64.1 (K), D65.1 (K), D66.1 (K), D67.1 (K), D68.1 (K), D69.1 (K), D70.1 (K), D71.1 (K), J1.4, J2.18, J3.11, J4.7
Y10: D79.1 (K), J3.2, J4.15, LK1.3 (B), LK2.1, LK6.2

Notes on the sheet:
Cursors + numpad
CPC464
PIN 11
Mounting holes to main casing
PIN 10
PIN 1
Extra mounting holes for free- standing use
Keycap sizes 464 This board Tab: 1.5u 1.5u Caps: 1.75u 1.75u L-Shift: 2.25u 2.25u Backspace: 1.5u 1u Enter: ISO+1u ISO R-Shift: 2.25u 1.75u Space: 9u 7u
CPC6128
Stabilisers For L-Shift, Enter, BackSpace (if required), and Space Bar
Note: Use 3.5mm spacers for a keyboard plate
'464 with PCB keyboard
Notes: Pin labels as per the CPC mainboard schematic. Schematic as per service manuals. Obviously X9 and Y10 should be swapped _shrug_. Also, X8 and X9 are shorted on the CPC, so SW79 could be above SW71 without affecting anything. And, on my 6128, Y9 is not present on the ribbon connector.
'664 (untested) (For info only, not on PCB)
Bonus Buttons
CPC464 or CPC6128 membrane keyboard
Main keyboard
CPC Modular (Same pinout as '6128)
PIN 20
Mounting holes for keyboard plate (Possible future option)

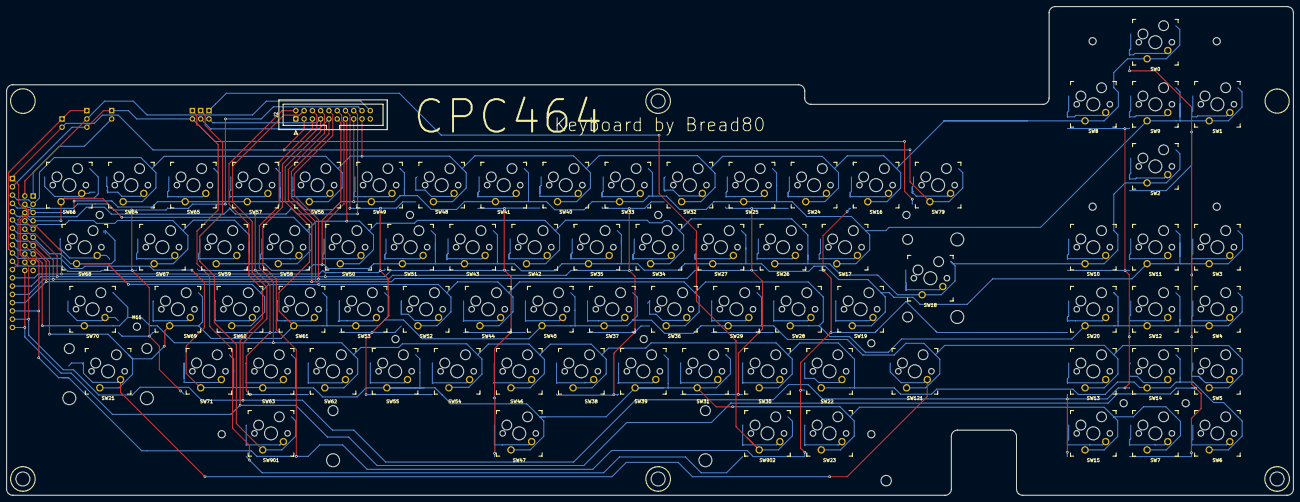
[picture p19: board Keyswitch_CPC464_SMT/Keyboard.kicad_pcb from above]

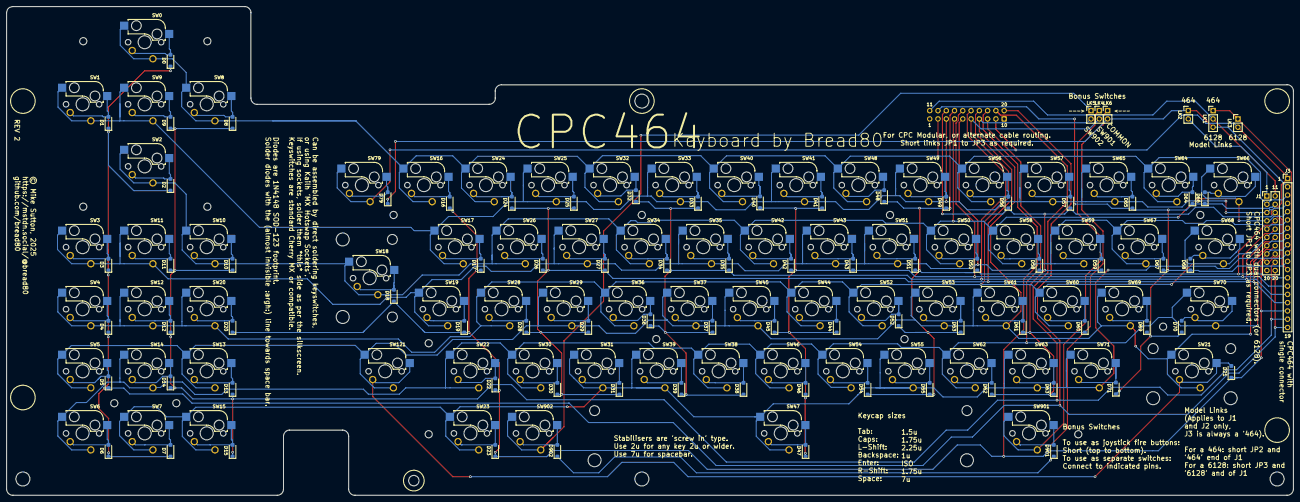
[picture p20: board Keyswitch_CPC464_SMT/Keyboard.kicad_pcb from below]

Board: 2 copper layers, 395.0 x 150.0 mm, 188 parts (83 on the bottom side), 99 nets.

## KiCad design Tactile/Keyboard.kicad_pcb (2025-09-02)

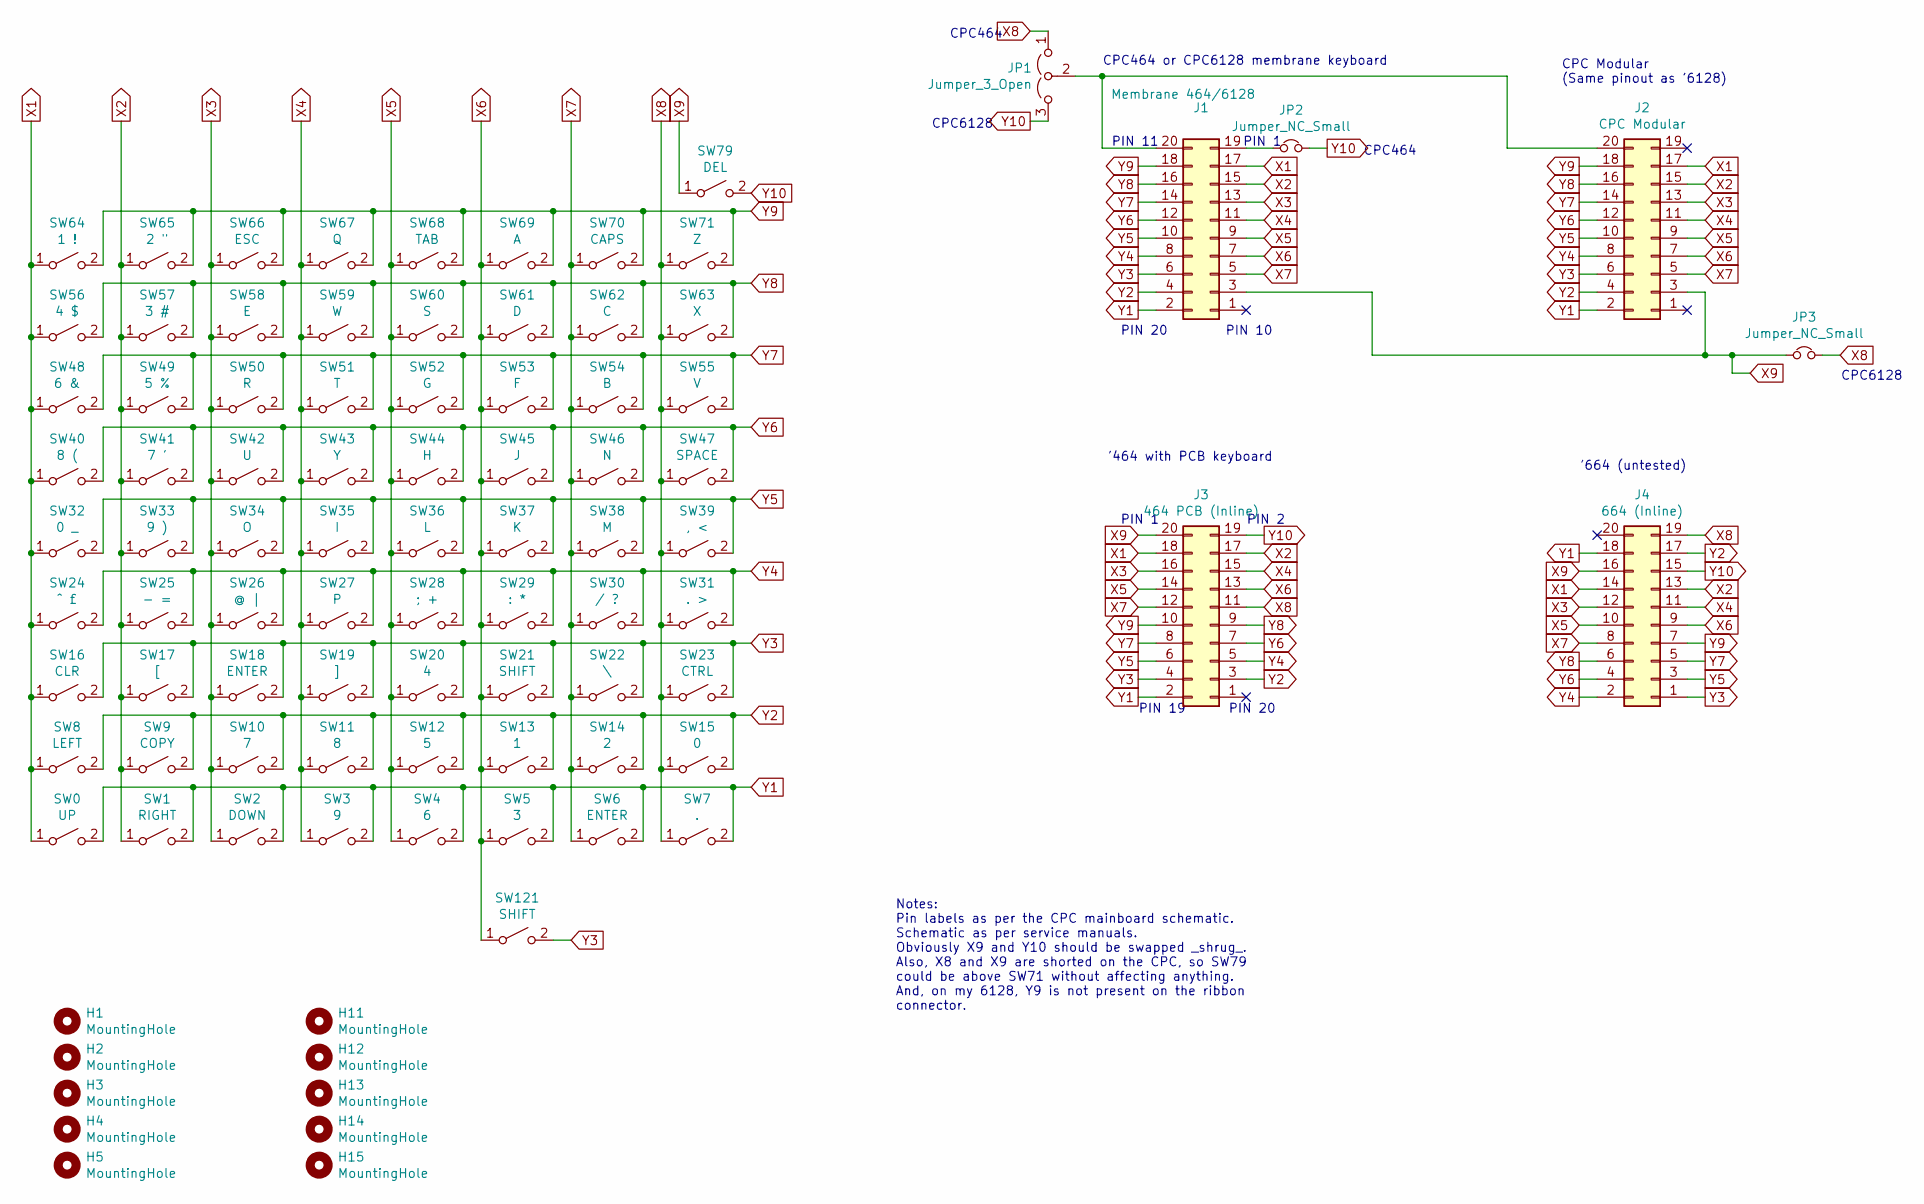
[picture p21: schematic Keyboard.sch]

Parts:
H1, H2, H3, H4, H5, H11, H12, H13, H14, H15: MountingHole; MountingHole_3.2mm_M3_DIN965
J1: Membrane 464/6128; IDC-Header_2x10_P2.54mm_Vertical
J2: CPC Modular; IDC-Header_2x10_P2.54mm_Vertical
J3: 464 PCB (Inline); IDC-Header_2x10_P2.54mm_Vertical
J4: 664 (Inline); IDC-Header_2x10_P2.54mm_Vertical
JP1: Jumper_3_Open; PinHeader_1x03_P2.54mm_Vertical
JP2, JP3: Jumper_NC_Small; PinHeader_1x02_P2.54mm_Vertical
SW0: UP; SKHCBEA010
SW1: RIGHT; SKHCBEA010
SW2: DOWN; SKHCBEA010
SW3: 9; SKHCBEA010
SW4: 6; SKHCBEA010
SW5: 3; SKHCBEA010
SW6, SW18: ENTER; SKHCBEA010
SW7: .; SKHCBEA010
SW8: LEFT; SKHCBEA010
SW9: COPY; SKHCBEA010
SW10: 7; SKHCBEA010
SW11: 8; SKHCBEA010
SW12: 5; SKHCBEA010
SW13: 1; SKHCBEA010
SW14: 2; SKHCBEA010
SW15: 0; SKHCBEA010
SW16: CLR; SKHCBEA010
SW17: [; SKHCBEA010
SW19: ]; SKHCBEA010
SW20: 4; SKHCBEA010
SW21, SW121: SHIFT; SKHCBEA010
SW22: \\; SKHCBEA010
SW23: CTRL; SKHCBEA010
SW24: ^ £; SKHCBEA010
SW25: - =; SKHCBEA010
SW26: @ |; SKHCBEA010
SW27: P; SKHCBEA010
SW28: ; +; SKHCBEA010
SW29: : *; SKHCBEA010
SW30: / ?; SKHCBEA010
SW31: . >; SKHCBEA010
SW32: 0 _; SKHCBEA010
SW33: 9 ); SKHCBEA010
SW34: O; SKHCBEA010
SW35: I; SKHCBEA010
SW36: L; SKHCBEA010
SW37: K; SKHCBEA010
SW38: M; SKHCBEA010
SW39: , <; SKHCBEA010
SW40: 8 (; SKHCBEA010
SW41: 7 '; SKHCBEA010
SW42: U; SKHCBEA010
SW43: Y; SKHCBEA010
SW44: H; SKHCBEA010
SW45: J; SKHCBEA010
SW46: N; SKHCBEA010
SW47: SPACE; SKHCBEA010
SW48: 6 &; SKHCBEA010
SW49: 5 %; SKHCBEA010
SW50: R; SKHCBEA010
SW51: T; SKHCBEA010
SW52: G; SKHCBEA010
SW53: F; SKHCBEA010
SW54: B; SKHCBEA010
SW55: V; SKHCBEA010
SW56: 4 $; SKHCBEA010
SW57: 3 #; SKHCBEA010
SW58: E; SKHCBEA010
SW59: W; SKHCBEA010
SW60: S; SKHCBEA010
SW61: D; SKHCBEA010
SW62: C; SKHCBEA010
SW63: X; SKHCBEA010
SW64: 1 !; SKHCBEA010
SW65: 2 \"; SKHCBEA010
SW66: ESC; SKHCBEA010
SW67: Q; SKHCBEA010
SW68: TAB; SKHCBEA010
SW69: A; SKHCBEA010
SW70: CAPS; SKHCBEA010
SW71: Z; SKHCBEA010
SW79: DEL; SKHCBEA010

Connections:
unnamed: J1.19, JP2.2
unnamed: J1.20, J2.20, JP1.2 (C)
X1: J1.17, J2.17, J3.18, J4.14, SW0.1 (A), SW8.1 (A), SW16.1 (A), SW24.1 (A), SW32.1 (A), SW40.1 (A), SW48.1 (A), SW56.1 (A), SW64.1 (A)
X2: J1.15, J2.15, J3.17, J4.13, SW1.1 (A), SW9.1 (A), SW17.1 (A), SW25.1 (A), SW33.1 (A), SW41.1 (A), SW49.1 (A), SW57.1 (A), SW65.1 (A)
X3: J1.13, J2.13, J3.16, J4.12, SW2.1 (A), SW10.1 (A), SW18.1 (A), SW26.1 (A), SW34.1 (A), SW42.1 (A), SW50.1 (A), SW58.1 (A), SW66.1 (A)
X4: J1.11, J2.11, J3.15, J4.11, SW3.1 (A), SW11.1 (A), SW19.1 (A), SW27.1 (A), SW35.1 (A), SW43.1 (A), SW51.1 (A), SW59.1 (A), SW67.1 (A)
X5: J1.9, J2.9, J3.14, J4.10, SW4.1 (A), SW12.1 (A), SW20.1 (A), SW28.1 (A), SW36.1 (A), SW44.1 (A), SW52.1 (A), SW60.1 (A), SW68.1 (A)
X6: J1.7, J2.7, J3.13, J4.9, SW5.1 (A), SW13.1 (A), SW21.1 (A), SW29.1 (A), SW37.1 (A), SW45.1 (A), SW53.1 (A), SW61.1 (A), SW69.1 (A), SW121.1 (A)
X7: J1.5, J2.5, J3.12, J4.8, SW6.1 (A), SW14.1 (A), SW22.1 (A), SW30.1 (A), SW38.1 (A), SW46.1 (A), SW54.1 (A), SW62.1 (A), SW70.1 (A)
X8: J3.11, J4.19, JP1.1 (A), JP3.1, SW7.1 (A), SW15.1 (A), SW23.1 (A), SW31.1 (A), SW39.1 (A), SW47.1 (A), SW55.1 (A), SW63.1 (A), SW71.1 (A)
X9: J1.3, J2.3, J3.20, J4.16, JP3.2, SW79.1 (A)
Y1: J1.2, J2.2, J3.2, J4.18, SW0.2 (B), SW1.2 (B), SW2.2 (B), SW3.2 (B), SW4.2 (B), SW5.2 (B), SW6.2 (B), SW7.2 (B)
Y2: J1.4, J2.4, J3.3, J4.17, SW8.2 (B), SW9.2 (B), SW10.2 (B), SW11.2 (B), SW12.2 (B), SW13.2 (B), SW14.2 (B), SW15.2 (B)
Y3: J1.6, J2.6, J3.4, J4.1, SW16.2 (B), SW17.2 (B), SW18.2 (B), SW19.2 (B), SW20.2 (B), SW21.2 (B), SW22.2 (B), SW23.2 (B), SW121.2 (B)
Y4: J1.8, J2.8, J3.5, J4.2, SW24.2 (B), SW25.2 (B), SW26.2 (B), SW27.2 (B), SW28.2 (B), SW29.2 (B), SW30.2 (B), SW31.2 (B)
Y5: J1.10, J2.10, J3.6, J4.3, SW32.2 (B), SW33.2 (B), SW34.2 (B), SW35.2 (B), SW36.2 (B), SW37.2 (B), SW38.2 (B), SW39.2 (B)
Y6: J1.12, J2.12, J3.7, J4.4, SW40.2 (B), SW41.2 (B), SW42.2 (B), SW43.2 (B), SW44.2 (B), SW45.2 (B), SW46.2 (B), SW47.2 (B)
Y7: J1.14, J2.14, J3.8, J4.5, SW48.2 (B), SW49.2 (B), SW50.2 (B), SW51.2 (B), SW52.2 (B), SW53.2 (B), SW54.2 (B), SW55.2 (B)
Y8: J1.16, J2.16, J3.9, J4.6, SW56.2 (B), SW57.2 (B), SW58.2 (B), SW59.2 (B), SW60.2 (B), SW61.2 (B), SW62.2 (B), SW63.2 (B)
Y9: J1.18, J2.18, J3.10, J4.7, SW64.2 (B), SW65.2 (B), SW66.2 (B), SW67.2 (B), SW68.2 (B), SW69.2 (B), SW70.2 (B), SW71.2 (B)
Y10: J3.19, J4.15, JP1.3 (B), JP2.1, SW79.2 (B)

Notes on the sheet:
Notes: Pin labels as per the CPC mainboard schematic. Schematic as per service manuals. Obviously X9 and Y10 should be swapped _shrug_. Also, X8 and X9 are shorted on the CPC, so SW79 could be above SW71 without affecting anything. And, on my 6128, Y9 is not present on the ribbon connector.
CPC464 or CPC6128 membrane keyboard
CPC464
CPC6128
PIN 11
PIN 20
PIN 1
PIN 10
CPC Modular (Same pinout as '6128)
'464 with PCB keyboard
'664 (untested)
PIN 19
PIN 2

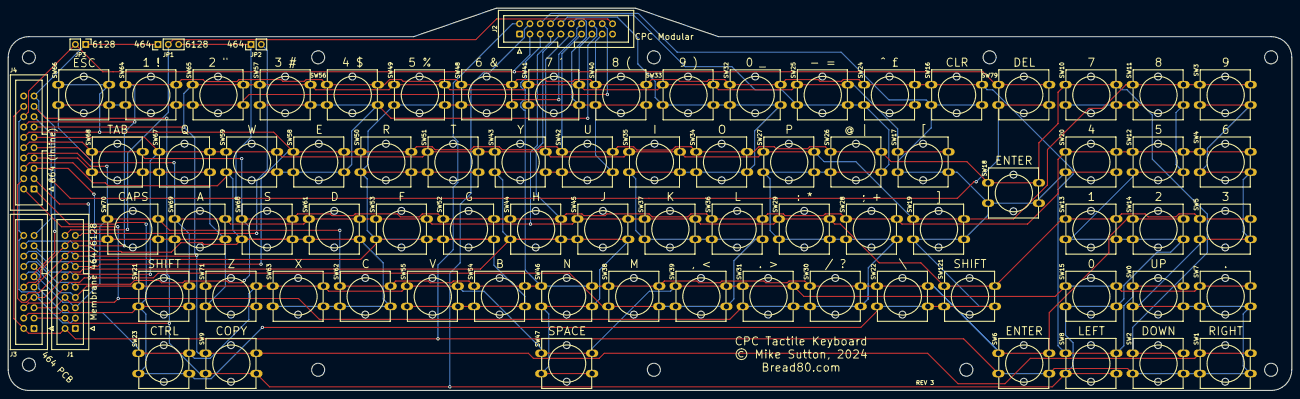
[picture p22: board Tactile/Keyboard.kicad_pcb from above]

Board: 2 copper layers, 315.6 x 94.0 mm, 91 parts (0 on the bottom side), 21 nets.

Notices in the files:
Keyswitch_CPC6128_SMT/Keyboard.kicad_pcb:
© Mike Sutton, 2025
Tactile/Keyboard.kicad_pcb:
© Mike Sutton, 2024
